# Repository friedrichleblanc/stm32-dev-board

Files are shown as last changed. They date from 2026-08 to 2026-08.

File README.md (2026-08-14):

# Stm32-dev-board
6-layer STM32H750 development board designed for embedded systems experimentation.

## Hardware Design Desicions
### STM32H750VBT6 Development Board

### Main MCU

STM32H750VBT6 is probably an overkill for this project. But i used it anyway so i maybe use other pins if need to.
Package: LQFP-100

[Click for more ](HardwareDesignDecisions.md)

## Schematics 

[Schematics](Doc/STM32H750VBT6schematics.pdf)

## Images

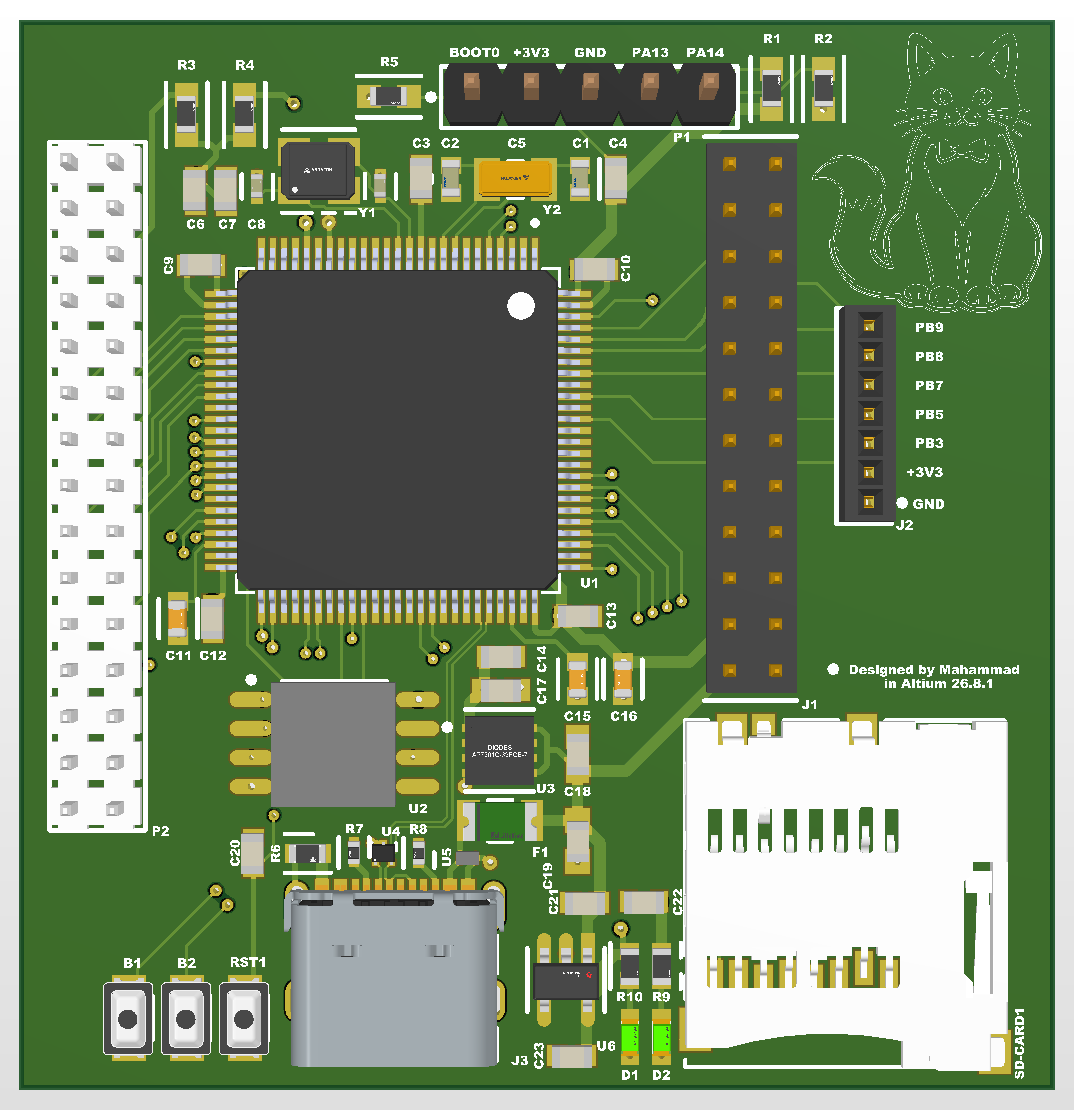
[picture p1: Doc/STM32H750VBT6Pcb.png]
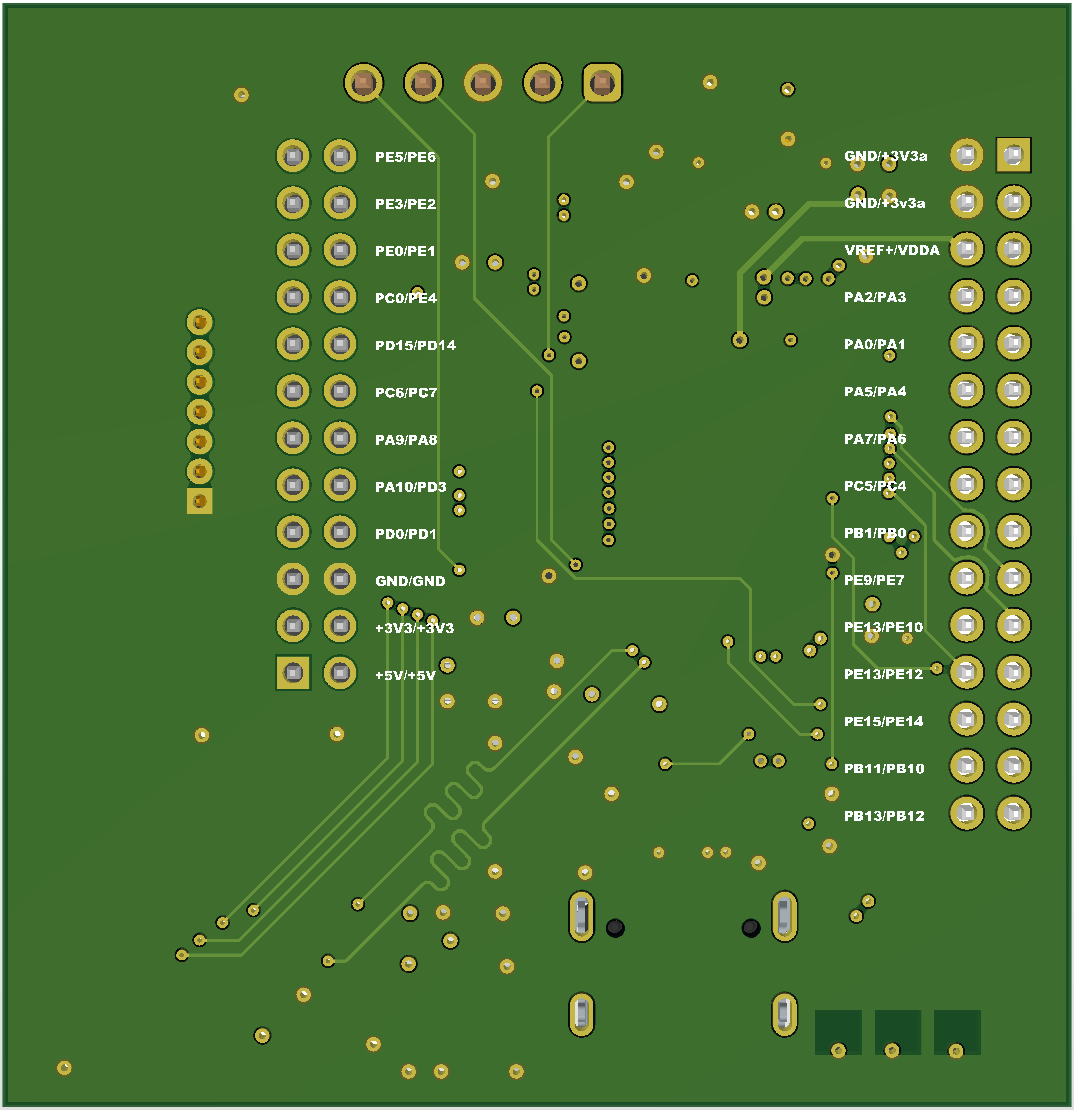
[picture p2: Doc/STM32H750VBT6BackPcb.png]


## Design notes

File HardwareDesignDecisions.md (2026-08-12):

# STM32H750VBT6 Development Board

## Main MCU

STM32H750VBT6 is probably an overkill for this project. But i used it anyway so i maybe use other pins if need to.
Package: LQFP-100

## Power

It can be powered by USB-C and will be with pins in future version. It has 2 power rails due to have 2 keep noise digital from analog. i could have used ferrite beads but i have personal beef with them. 

### Digital 3.3V LDO
  AP7361C 3.3V@1A is used for Digital
  
### Analog 3.3V LDO
  TLV73333 3.3V@300mA is used for Analog parts

##   External Flash 
W25Q128- 128 MBit QSPI flash.

## MicroSD 
(473521001) is SDMMC that requires length tuning. 

## ESD Protection

TPD2EUSB30DRTR - is used for safety for DATA traces
TPD1E10B06DPYT - is used for safety of USB 5V power trace

## Buttons

#B1 and B2 is on pins PD8 and PD9 so you can add whatever function you want to those. Basically, RST button basically resets the board.

## Stackup and Routing

6 layer offers improved grounding, routing space, signal integrity. Orthogonal routing strategy was partially applied.

Signal Traces/Power
\
GND Copper Pour
\
Signal Traces/Power
\
Signal Traces/Power
\
GND Copper Pour
\
Signal Traces/Power

## SWD Debugging and Programming

it has 5 pins :

BOOT0 / +3V3 / GND / PA13 / PA14

## Exposed pins

PA: PA0, PA1, PA2, PA3, PA8, PA9, PA10, PA15

PB: PB0, PB1, PB10, PB11, PB12, PB13, PB14, PB15

PC: PC0, PC1, PC4, PC5, PC6, PC7

PD: PD0, PD1, PD2, PD3, PD4, PD5, PD6, PD7, PD8, PD9, PD10, PD14, PD15

PE: PE0, PE1, PE2, PE3, PE4, PE5, PE6, PE7, PE9, PE10, PE11, PE12, PE13, PE14, PE1

also both digital and analog +3v3 and +5v. ~couple of grounds:)

## OLED interface.

SSD1306  is planned to use and have dedicated port in right side of the board.

## Clocks

ABM8G-25.000MHZ-18-D2Y-T - 25 MHZ crystal used as the main high-speed clock for the MCU

ABS07-32.768KHZ-T - 32.768 kHz crystal used for low-frequency timing and RTC.

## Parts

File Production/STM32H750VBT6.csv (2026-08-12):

Name | Description | Designator | Footprint | LibRef | Quantity
EVP-AWBD4A | 3.0MM X 2.0MM / 1.6N / 0.13MM ST | B1, B2, RST1 | FP-EVP-AWBD4A-MFG | CMP-05618-000071-1 | 3
20pF | CAP CER 20PF 100V NP0 0603 | C1, C2 | FP-C0603C-CF-MFG | CMP-1035-00786-2 | 2
100nF | CAP 100nF 10V ±5% 0603 (1608 Metric) Thickness 1mm SMD | C3, C4, C6, C9, C10, C12, C13, C14, C22 | CAPC0603(1608)100_L | CMP-1035-02579-1 | 9
27pF | Cap Ceramic 27pF 50V C0G 5% SMD 0402 125°C Paper T/R | C5, C8 | FP-AC0402-0_5-MFG | CMP-03422-000367-1 | 2
1uF |  | C7 | CAPC1608X90X35LL15T15 | CMP-2006-04194-1 | 1
2.2uF | CC0603 2.2 uF X5R 10.00% 16 V | C11, C15 | FP-CC0603-DA-MFG | CMP-03422-000187-1 | 2
4.7uF | CC0603 4.7 uF X5R 10.00% 6.3 V | C16 | FP-CC0603-DA-MFG | CMP-03422-000953-1 | 1
0603ZD475MAT2A |  | C17, C18 | CAPC1608X90X35NL15T15 | CMP-1035-02787-2 | 2
CAP 10uF 6.3V 0603(1608) | CAP 10uF 6.3V ±10% 0603 (1608 Metric) Thickness 1mm SMD | C19 | CAPC0603(1608)100_M | CMP-1035-02796-1 | 1
0.1uF | CAP 100nF 10V ±5% 0603 (1608 Metric) Thickness 1mm SMD | C20 | CAPC0603(1608)100_L | CMP-1035-02579-1 | 1
06033D105MAT2A |  | C21, C23 | CAPC1608X90X35LL15T15 | CMP-2006-04194-1 | 2
APT1608LZGCK | LED GREEN CLEAR 2SMD | D1, D2 | FP-APT1608LZGCK-MFG | CMP-44529-000040-1 | 2
1206L050YR | PTC RESET FUSE 6V 500MA 1206 | F1 | FP-1206L050YR-MFG | CMP-08606-000073-1 | 1
TMM-112-05-L-D | 2MM TERMINAL STRIP | J1 | FP-TMM-112-05-L-D-MFG | CMP-02766-001490-1 | 1
OLED | LPPB071NFFN-RC .050 Female Header 1 Row 1x07 pins Straight | J2 | FP-LPPB071NFFN-RC-MFG | CMP-00595-12086171-1 | 1
629722000214 | Usb Conn, R/a, Type C 2.0, Rcpt, 16POS Rohs Compliant: Yes | J3 | 629722000214 | CMP-207978-000003-3 | 1
61300511121 | THT Vertical Pin Header WR-PHD, Pitch 2.54 mm, Single Row, 5 pins | P1 | 61300511121 | CMP-1502-01068-4 | 1
TMM-115-02-S-D | Low Profile Through-Hole Header, Vertical, -55 to 125 degC, 2 mm Pitch, 30-Pin, Male, RoHS | P2 | SMTC-TMM-115-02-X-D | CMP-1029-00203-1 | 1
10K | RES 10kO 5.00% 0.2W 0603 | R1, R2, R5 | FP-AC0603-IPC_A | CMP-03412-040683-1 | 3
0 | RES 0O 0.00% 0.1W 0603 | R3, R4 | FP-AC0603-IPC_A | CMP-03412-047235-1 | 2
1M | RES 1M OHM 1% 1/4W 0603 | R6 | FP-CRGP0603-IPC_C | CMP-03211-004384-3 | 1
5.1K | 5.1kO ±1% 0.063W, 1/16W Chip Resistor 0402 (1005 Metric) Moisture Resistant Thin Film | R7, R8 | FP-RN73R1E-IPC_C | CMP-04015-008529-1 | 2
CR0603AFX-3570EAS | Sulfur-Resistant, AEC-Q200 Compliant Chip Resistors 0603 357O 0.1W 1% 100ppm/°C | R9, R10 | FP-CR0603-IPC_C | CMP-07231-001527-1 | 2
473521001 | MicroSD(TM), Pitch 1.1 mm, 8 Position, Height 1.88 mm, -20 to 85 degC, RoHS, Tape and Reel | SD-CARD1 | MOLX-473521001_V | CMP-2000-05848-1 | 1
STM32H750VBT6 | High-performance and DSP with DP-FPU, Arm Cortex-M7 MCU with 128 Kbytes of Flash memory, 1MB RAM, 480 MHz CPU, L1 cache, external memory interface, JPEG codec, HW crypto, large set of peripherals | U1 | QFP50P1600X1600X160-100N | STM32H750VBT6 | 1
W25Q128FVSIG | 3V 128M-Bit Serial Flash Memory with Dual/Quad SPI & QPI, 2.7 to 3.6 V, -40 to 85 degC, 8-Pin SOIC, RoHS, Tape and Reel | U2 | WINB-SOIC-8_M | CMP-2000-05005-1 | 1
AP7361C-33FGE-7 | IC REG LINEAR 3.3V 1A UDFN3030-8 | U3 | FP-U-DFN3030-8_Type_E-MFG | CMP-12756-000002-1 | 1
TPD2EUSB30DRTR | ESD Solution for Super-Speed (6 Gbps) USB 3.0 Interface, 2 Channels, -40 to +85 degC, 3-pin SOT (DRT), Green (Rohs & No Sb/Br) | U4 | DRT0003A | CMP-0326-00046-3 | 1
TPD1E10B06DPYT | ESD Protection in 0402 Package with 10 pF Capacitance and 6 V Breakdown, 1 Channel, -40 to +125 degC, 2-pin X2SON (DPY) | U5 | DPY0002A_L | CMP-0326-00006-3 | 1
TLV73333PQDBVRQ1 | IC REG LINEAR 3.3V 300MA SOT23-5 | U6 | FP-DBV0005A-IPC_A | CMP-04917-000347-1 | 1
ABM8G-25.000MHZ-18-D2Y-T | Crystal 25MHz ±20ppm (Tol) ±30ppm (Stability) 18pF FUND 60? 4-Pin SMD T/R | Y1 | FP-ABM8G-MFG | CMP-2000-05733-3 | 1
ABS07-32.768KHZ-T | Crystal 32.768kHz ±20ppm (Tol) 12.5pF FUND 70k? 2-Pin CSMD T/R | Y2 | FP-ABS07-MFG | CMP-0447-00001-4 | 1

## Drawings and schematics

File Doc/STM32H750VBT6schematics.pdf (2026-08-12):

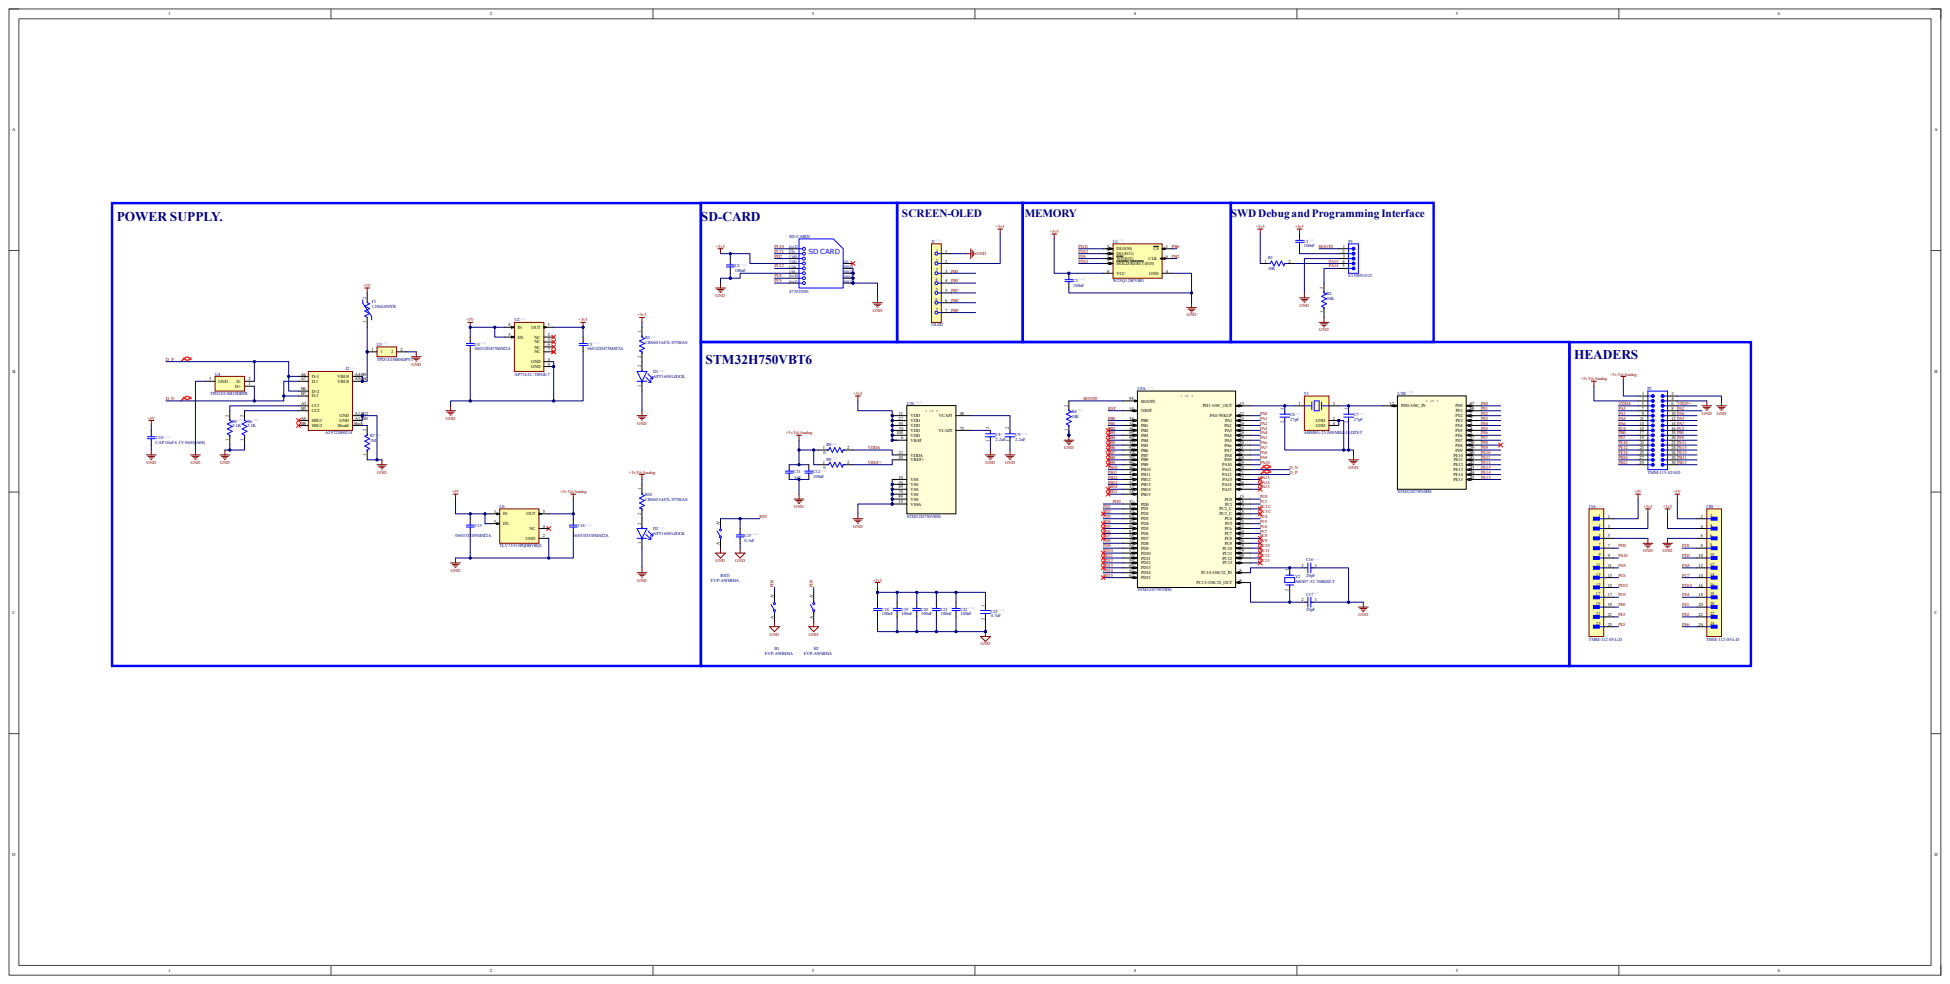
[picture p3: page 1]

SWD Debug and Programming Interface

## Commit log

2026-08-12 Rename STM32H750VBT6 Pcb.png to STM32H750VBT6Pcb.png
2026-08-12 Rename STM32H750VBT6back Pcb.png to STM32H750VBT6BackPcb.png
2026-08-12 Fix formatting of Schematics section in README
2026-08-12 Update heading level for STM32H750VBT6 section
2026-08-14 Update schematics link in README
